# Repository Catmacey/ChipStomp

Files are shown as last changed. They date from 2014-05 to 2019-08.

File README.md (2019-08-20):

ChipStomp Guitar Effects Pedal
==============================

ChipStomp

This is a digital guitar effects pedal based on the Arduino compatible Chipkit DP32 platform.
The project is a merging of a ChipKit DP32 with an Open Music Labs Stompshield in a custom build PCB.

The Chipkit is an arduino compatible platform powered by a 32bit Microchip PIC processor running at 40Mhz with 32Kb RAM and 128Kb flash.  

UPDATE: There is a [3d printable case available for this project](https://github.com/Catmacey/ChipStompCase). 
3D Printed Case

The project is relatively simple in that it limits itself to using the PIC's internal RAM, built in 10bit ADC and utilizes two 8bit PWMs to form a single 16bit output.  Also included is a 128x64px 1.3" OLED to provide a nice user interface.

Currently the following effects are completed.
- **Flanger** : Classic wobbly tape effect.

- **Tremolo** : Low frequency modulation of the source audio.

- **Pitch shift** : Change the pitch (up or down) of the source audio without changing the playback speed.

- **Echo/Delay** : A simple lo-fi delay (700ms Max) that when combined with a bit of analogue feedback provides a nice echo.

- **Bitcrusher** : Reduces the sample rate by ratios down to 1/64 of the source rate, also reduces the bit-depth to create some nice messy sounds.

You can have all or just some of these effect running at the same time with each passing its output onto the next effects input. 

[More information is available on my blog.](http://catmacey.wordpress.com/tag/chipstomp/)

Copyright (C) 2014 Matt Casey : catmacey.com
This program is free software: you can redistribute it and/or modify it under the terms of the GNU General Public License as published by the Free Software Foundation, either version 3 of the License, or (at your option) any later version.
	
This program is distributed in the hope that it will be useful, but WITHOUT ANY WARRANTY; without even the implied warranty of MERCHANTABILITY or FITNESS FOR A PARTICULAR PURPOSE.  See the GNU General Public License for more details.

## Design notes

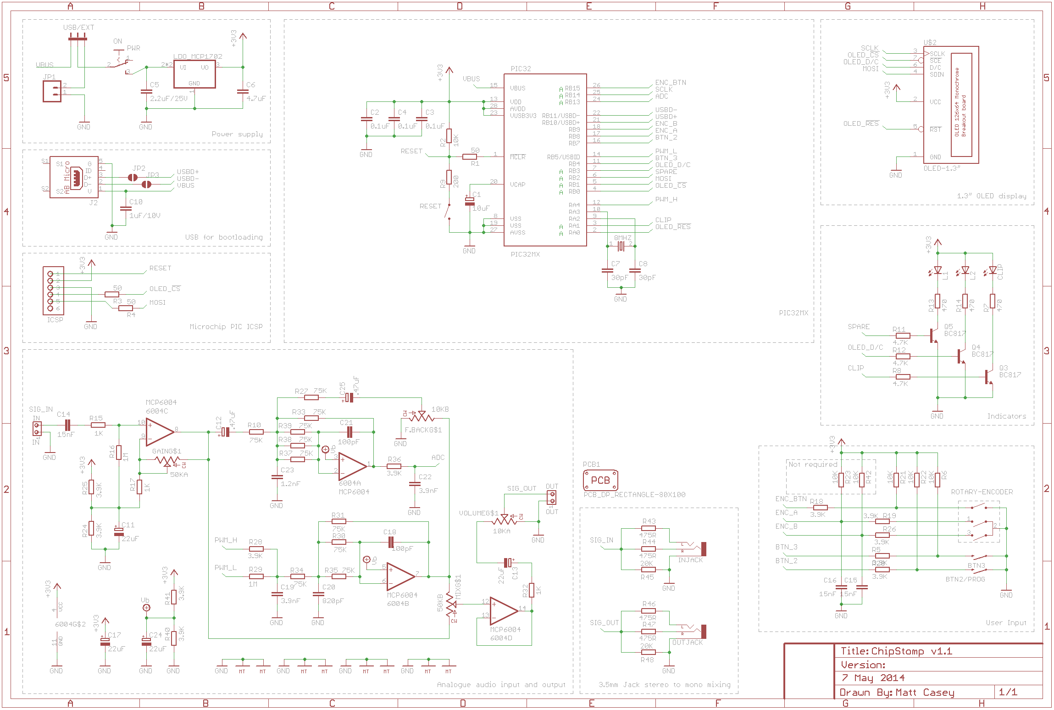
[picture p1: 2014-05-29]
EagleCad/Schematic_v1.1.png

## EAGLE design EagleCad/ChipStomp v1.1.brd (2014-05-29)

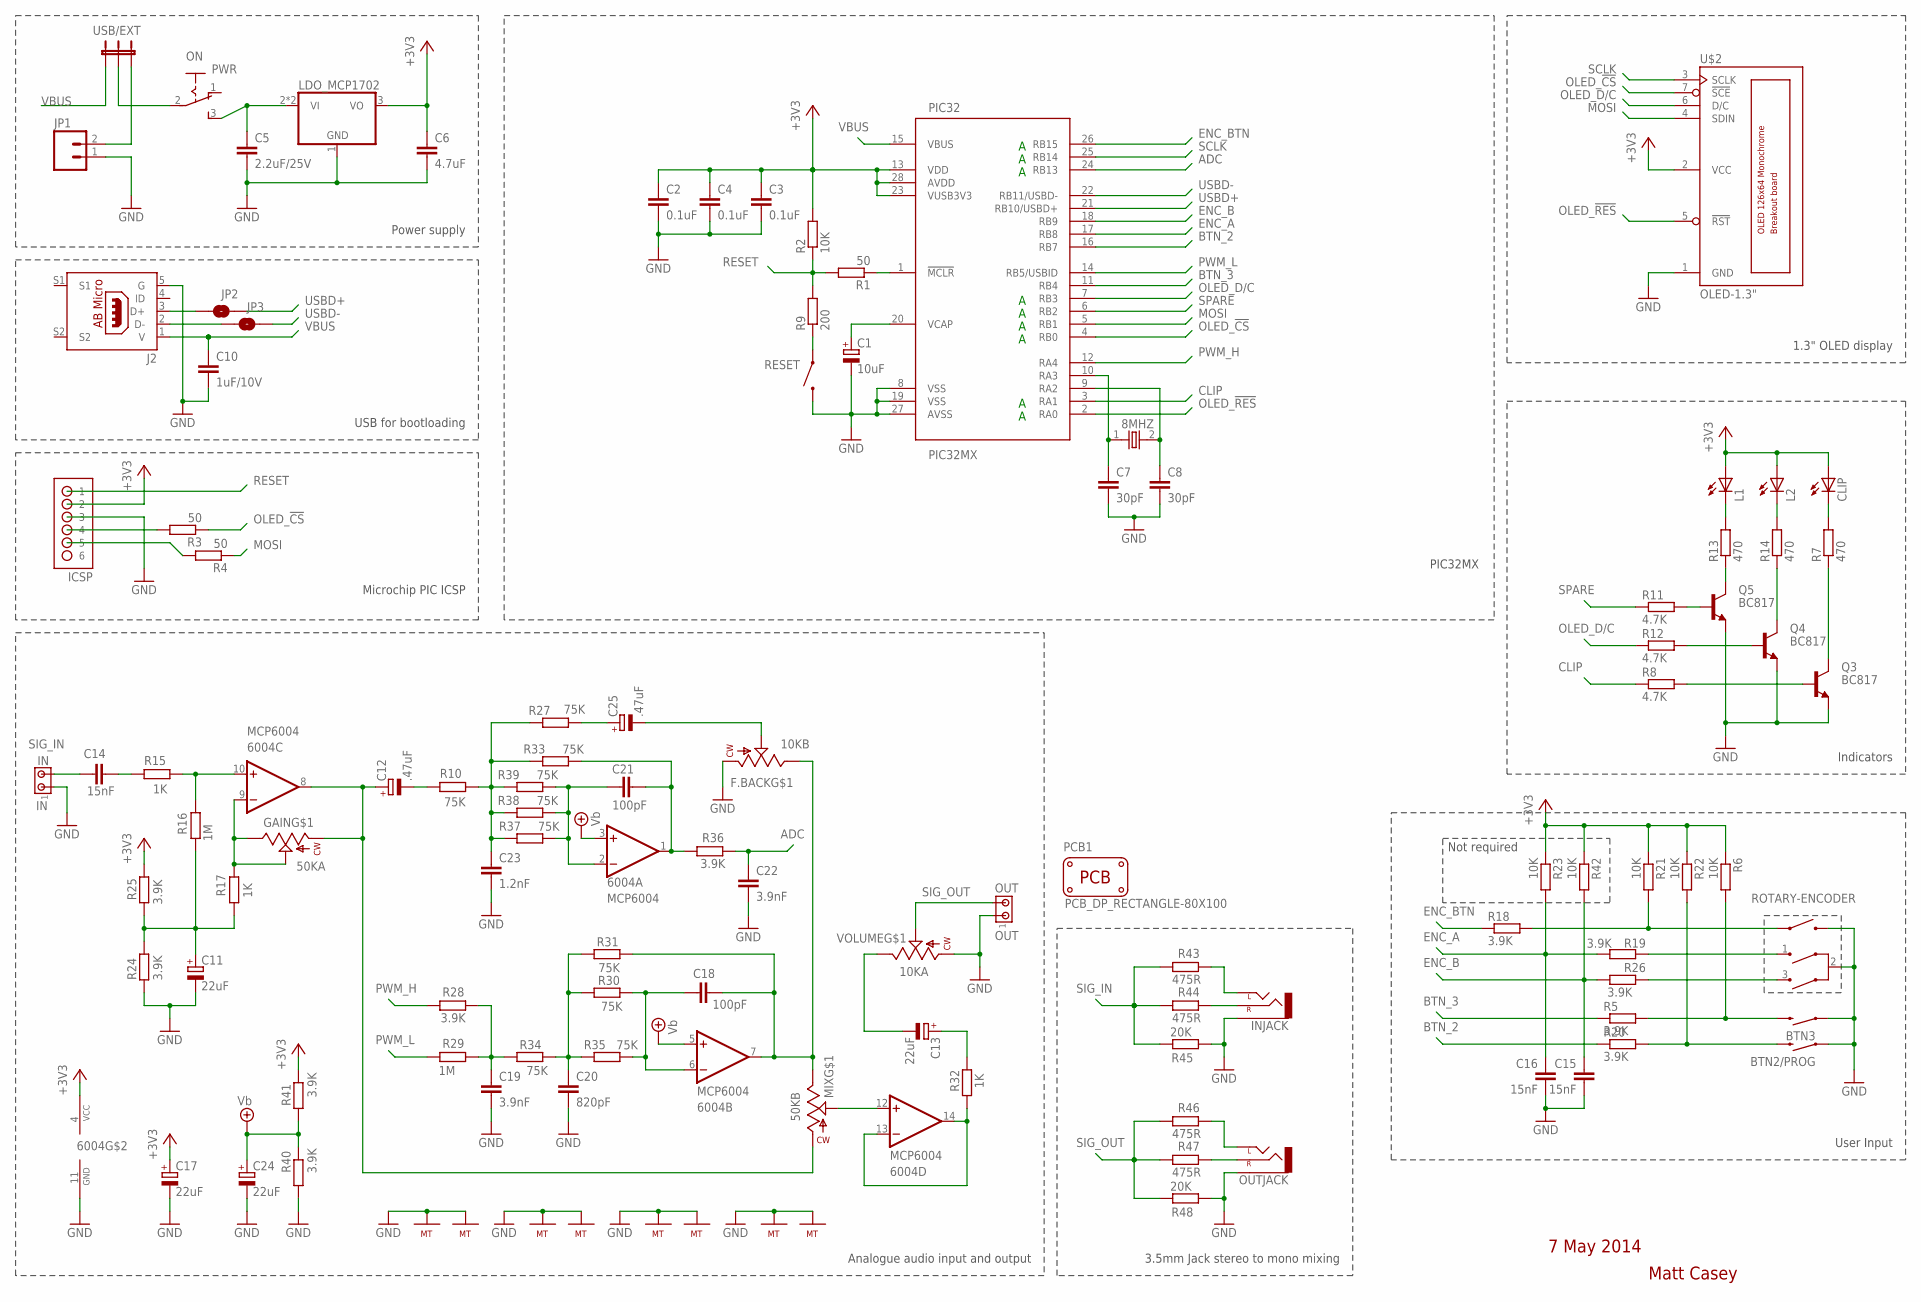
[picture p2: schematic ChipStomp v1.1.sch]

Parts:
8MHZ: OSC-XTAL-HC-49U-SMD; HC-49U
6004: MCP6004; SO-14
BTN2/PROG, BTN3: SWITCH-MOMENTARY-212MM; TACTILE-PTH-12MM
C1: 10uF; A/3216-18R
C2, C3, C4: 0.1uF; C0805K
C5: 2.2uF/25V; C0805K
C6: 4.7uF; C0805K
C7, C8: 30pF; C0805K
C10: 1uF/10V; C0805K
C11, C13, C17, C24: 22uF; 153CLV-0505
C12, C25: .47uF; 153CLV-0405
C14, C15, C16: 15nF; C0805K
C18, C21: 100pF; C0805K
C19, C22: 3.9nF; C0805K
C20: 820pF; C0805K
C23: 1.2nF; C0805K
CLIP: LED-0805; LED-805
F.BACK: 10KB; POT/SINGLE/PANASONIC/VERT
GAIN: 50KA; POT/SINGLE/PANASONIC/VERT
ICSP: No Load; HDR-1X6_OFFSET
IN: IN; JMP/2P/SIP
INJACK: AUDIO-JACKPTH; STEREO_JACK3.5MM_PTH
J2: US-AB-MICRO-TH; WMRU2AB-05FLB2DSR-4.0
JP1: M023.5MM; SCREWTERMINAL-3.5MM-2
JP2, JP3: Straight Male; SJ_2S-TRACE
L1, L2: LED-0805; LED-805
MIX: 50KB; POT/SINGLE/PANASONIC/VERT
ON: PWR; DX_MINI_SPDT_VERTICAL
OUT: OUT; JMP/2P/SIP
OUTJACK: AUDIO-JACKPTH; STEREO_JACK3.5MM_PTH
PCB1: PCB_DP_RECTANGLE-80X100; DP10080_V1
PIC32: PIC32MX; SO-28
Q3, Q4, Q5: BC817; SOT23-BEC
R1, R3, R4: 50; R0805
R2, R6, R21, R22, R23, R42: 10K; R0805
R5, R18, R19, R20, R24, R25, R26, R28, R36, R40, R41: 3.9K; R0805
R7, R13, R14: 470; R0805
R8, R11, R12: 4.7K; R0805
R9: 200; R0805
R10, R27, R30, R31, R33, R34, R35, R37, R38, R39: 75K; R0805
R15, R17, R32: 1K; R0805
R16, R29: 1M; R0805
R43, R44, R46, R47: 475R; R0805
R45, R48: 20K; R0805
RESET: TINY_TACTILEPTH; TINY_TACTILE_PTH
SW1: ROTARY-ENCODER; SURE
U$2: OLED-1.3"; OLED-130-BREAKOUT_2HOLES
U$3: LDO_MCP1702; SOT89
USB/EXT: JUMPER-3PTH; 1X03
VOLUME: 10KA; POT/SINGLE/PANASONIC/VERT

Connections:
+3V3: 6004.4 (VCC), C2.1, C3.1, C4.1, C6.1, C17.+, CLIP.A, ICSP.2, L1.A, L2.A, PIC32.13 (VDD), PIC32.23 (VUSB3V3), PIC32.28 (AVDD), R2.2, R6.1, R21.1, R22.1, R23.1, R25.1, R41.1, R42.1, U$2.2 (VCC), U$3.3 (VO)
ADC: C22.1, PIC32.24 (RB13), R36.1
BTN_2: PIC32.16 (RB7), R20.1
BTN_3: PIC32.11 (RB4), R5.1
CLIP: PIC32.3 (RA1), R8.1
ENC_A: C16.1, PIC32.17 (RB8), R19.1, R23.2
ENC_B: C15.1, PIC32.18 (RB9), R26.1, R42.2
ENC_BTN: PIC32.26 (RB15), R18.1
GND: 6004.11 (GND), BTN2/PROG.1, BTN3.1, C1.-, C2.2, C3.2, C4.2, C5.2, C6.2, C7.2, C8.2, C10.2, C11.-, C15.2, C16.2, C17.-, C19.2, C20.2, C22.2, C23.2, C24.-, F.BACK.P$1 (1), F.BACK.P$4 (MT), F.BACK.P$5 (MT), GAIN.P$4 (MT), GAIN.P$5 (MT), ICSP.3, IN.1, INJACK.S (SLEEVE), INJACK.S@1 (SLEEVE), J2.5 (G), JP1.1, MIX.P$4 (MT), MIX.P$5 (MT), OUT.1, OUTJACK.S (SLEEVE), OUTJACK.S@1 (SLEEVE), PIC32.8 (VSS), PIC32.19 (VSS), PIC32.27 (AVSS), Q3.E, Q4.E, Q5.E, R24.2, R40.2, R45.2, R48.2, RESET.2 (B), SW1.2 (COMMON), SW1.A (B), U$2.1 (GND), U$3.1 (GND), VOLUME.P$1 (1), VOLUME.P$4 (MT), VOLUME.P$5 (MT)
MOSI: PIC32.5 (RB1), R4.1, U$2.4 (SDIN)
unnamed: PIC32.1 (!MCLR), R1.1
unnamed: BTN3.3 (2), R5.2, R6.2
unnamed: Q3.C, R7.1
unnamed: Q3.B, R8.2
unnamed: CLIP.C, R7.2
unnamed: INJACK.L (LEFT), INJACK.L@1 (LEFT), R43.1
unnamed: INJACK.R (RIGHT), R44.1
unnamed: ON.2, USB/EXT.2
unnamed: OUTJACK.L (LEFT), OUTJACK.L@1 (LEFT), R46.1
unnamed: R9.1, RESET.1 (A)
unnamed: C1.+, PIC32.20 (VCAP)
unnamed: OUTJACK.R (RIGHT), R47.1
unnamed: C14.2, R15.2
unnamed: JP1.2, USB/EXT.3
unnamed: 6004.10 (+IN), R15.1, R16.2
unnamed: Q5.B, R11.2
unnamed: Q5.C, R13.1
unnamed: Q4.C, R14.1
unnamed: Q4.B, R12.2
unnamed: 6004.8 (OUT), C12.+, GAIN.P$1 (1), MIX.P$1 (1)
unnamed: J2.2 (D-), JP3.1
unnamed: 6004.9 (-IN), GAIN.P$2 (2), GAIN.P$3 (3), R17.2
unnamed: L1.C, R13.2
unnamed: L2.C, R14.2
unnamed: C12.-, R10.2
unnamed: R18.2, R21.2, SW1.B (A)
unnamed: BTN2/PROG.3 (2), R20.2, R22.2
unnamed: C23.1, R10.1, R27.2, R33.2, R37.2, R38.2, R39.2
unnamed: 6004.2 (-IN), C21.1, R37.1, R38.1, R39.1
unnamed: 6004.1 (OUT), C21.2, R33.1, R36.2
unnamed: C11.+, R16.1, R17.1, R24.1, R25.2
unnamed: C19.1, R28.1, R29.1, R34.2
unnamed: C20.1, R30.2, R31.2, R34.1, R35.2
unnamed: 6004.6 (-IN), C18.1, R30.1, R35.1
unnamed: C25.+, R27.1
unnamed: 6004.7 (OUT), C18.2, F.BACK.P$3 (3), MIX.P$3 (3), R31.1
unnamed: C13.+, R32.1
unnamed: C13.-, VOLUME.P$3 (3)
unnamed: R19.2, SW1.1 (SIG1)
unnamed: R26.2, SW1.3 (SIG2)
unnamed: C25.-, F.BACK.P$2 (2)
unnamed: 6004.12 (+IN), MIX.P$2 (2)
unnamed: 6004.13 (-IN), 6004.14 (OUT), R32.2
OLED_!CS: PIC32.4 (RB0), R3.1, U$2.7 (!SCE)
OLED_!RES: PIC32.2 (RA0), U$2.5 (!RST)
OLED_D/C: PIC32.7 (RB3), R12.1, U$2.6 (D/C)
OSC1/CLKI/RPA2/RA2: 8MHZ.2, C8.1, PIC32.9 (RA2)
OSC2/CLKO/RPA3/PMA0/RA3: 8MHZ.1, C7.1, PIC32.10 (RA3)
PGC: ICSP.5, R4.2
PGD: ICSP.4, R3.2
PWM_H: PIC32.12 (RA4), R28.2
PWM_L: PIC32.14 (RB5/USBID), R29.2
RESET: ICSP.1, R1.2, R2.1, R9.2
SCLK: PIC32.25 (RB14), U$2.3 (SCLK)
SIG_IN: C14.1, IN.2, R43.2, R44.2, R45.1
SIG_OUT: OUT.2, R46.2, R47.2, R48.1, VOLUME.P$2 (2)
SPARE: PIC32.6 (RB2), R11.1
USBD+: J2.3 (D+), JP2.1, JP2.2, PIC32.21 (RB10/USBD+)
USBD-: JP3.2, PIC32.22 (RB11/USBD-)
VBUS: C10.1, J2.1 (V), PIC32.15 (VBUS), USB/EXT.1
VIN: C5.1, ON.3 (S), U$3.2 (VI), U$3.4 (VI)
VREF: 6004.3 (+IN), 6004.5 (+IN), C24.+, R40.1, R41.2

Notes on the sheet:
User Input
Power supply
Indicators
3.5mm Jack stereo to mono mixing
Analogue audio input and output
USB for bootloading
Microchip PIC ICSP
1.3" OLED display
Matt Casey
PIC32MX
7 May 2014
Not required

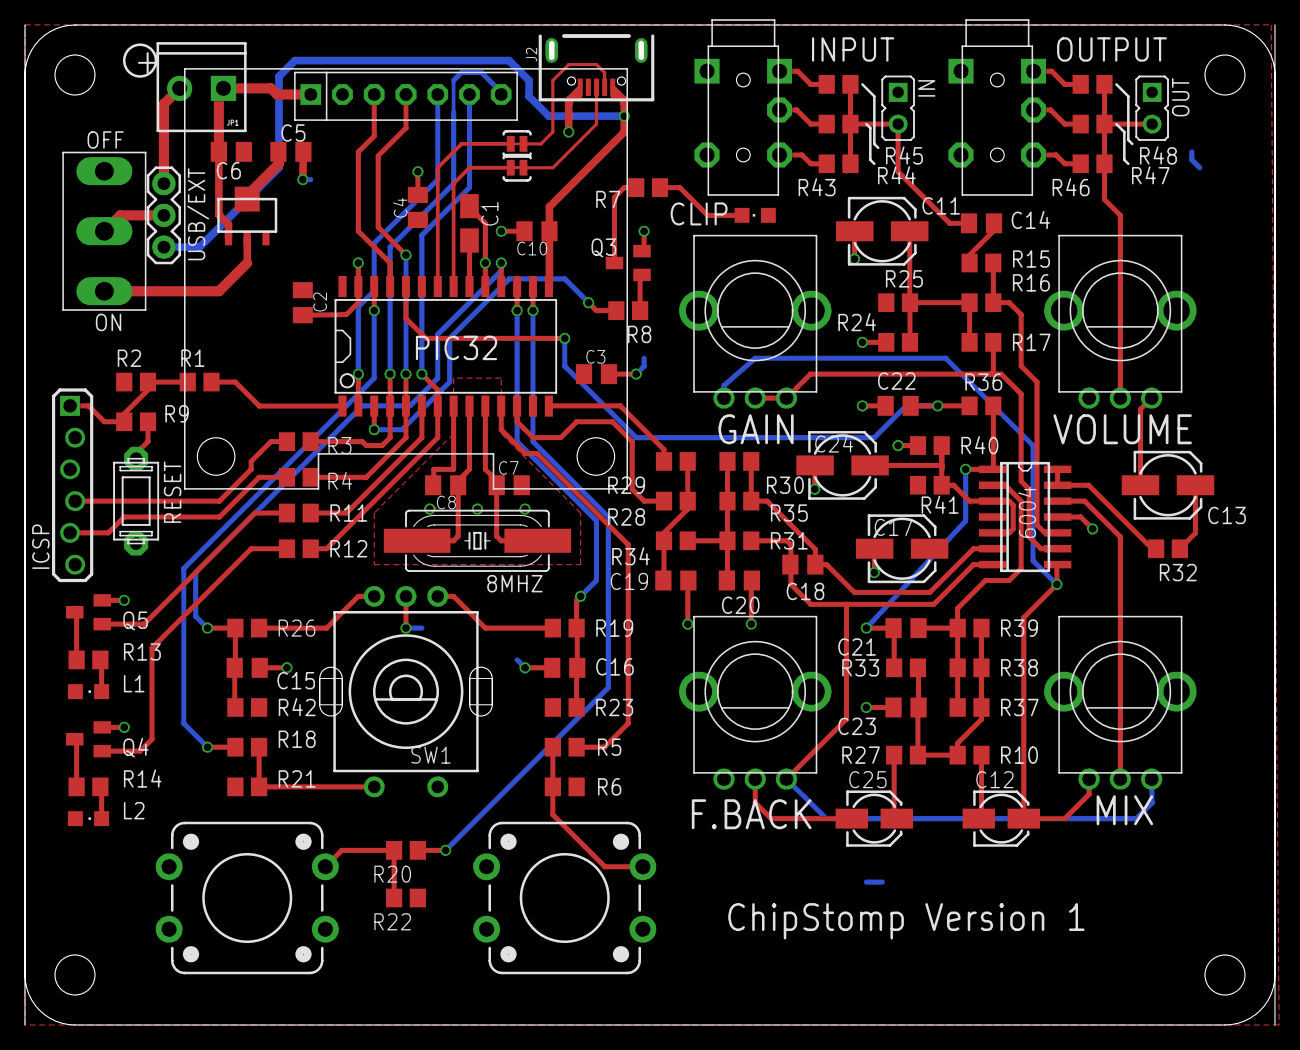
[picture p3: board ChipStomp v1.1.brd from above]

Board: 2 copper layers, 100.0 x 80.0 mm, 103 parts (0 on the bottom side), 72 nets.

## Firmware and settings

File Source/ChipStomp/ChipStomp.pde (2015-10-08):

// 
// ChipStomp
// Multifunction audio effects processor built on a Microchip PIC32MX
//

/*
	Reads mono audio in on the ADC
	Processes it with one or more digital effects
	Sends it out on two 8bit PWM summed together to form a 16bit mono output

	Hardware is a combination of the ChipKit DP32 and an Open Labs StompShield
	StompShield : Shield http://www.openmusiclabs.com/projects/stomp-shield/
	DP32 : https://digilentinc.com/Products/Detail.cfm?NavPath=2,892,1174&Prod=CHIPKIT-DP32
	Display is a 128x64 px SH1106 based OLED

	Copyright (C) 2014 Matt Casey : catmacey.com

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
	This program is distributed in the hope that it will be useful,
	but WITHOUT ANY WARRANTY; without even the implied warranty of
	MERCHANTABILITY or FITNESS FOR A PARTICULAR PURPOSE.  See the
	GNU General Public License for more details.
*/

#define VERSION "1.0"

#include <PLIB.h>  // Use this Microchip library to make access to the peripherals easier
#include <DSPI.h>
#include <Adafruit_GFX.h>
#include <Catmacey_SH1106.h>
#include "config.h"

// Include the font's you want here
#include "LiberationSans10.c"
// #include "LiberationMono11.c"
#include "DejaVuSans12.c"

// Make an array of pointers to FONT_INFOs for each font that you want
// Don't forget to put a NULL at the end
const FONT_INFO *g_font_table[] = {
		&liberationSans_10ptFontInfo
	, &dejaVuSans_12ptFontInfo
	, NULL
};


// Each effect is it's own self contained module
#include "Effect_typeDefs.h"
#include "effect_tremolo.h"
#include "effect_flanger.h"
#include "effect_echo.h"
#include "effect_bitcrush.h"
#include "effect_dummy.h"
#include "effect_pitchshift.h"
// #include "effect_sinus.h"

// Effects stack : Important that the last one is NULL so that we are a the end.
Effect_t *g_effects[] = {
			&effect_Tremolo
		, &effect_Flanger
		, &effect_Pitchshift
		, &effect_Bitcrush
		, &effect_Echo
		// , &effect_Sinus
		, NULL
	};

// TODO : Create a distortion effect with configuable threshold, shoft/hard clipping.
// TODO : Add a metronome effect (last in the chain) with config bpm/volume.
// TODO : Improve input sampling by oversampling (running ADC at faster rate then averaging the results)
// TODO : Add "cost" to each effect (measured using LA) to allow user to select effects that fit withing the overall CPU budget.
// TODO : Allow user to change order or load-out of effects to allow duplication of effects?
// TODO : Allow user to save their current config and effect values. Provide interface to load these saves.
// TODO : Bandpass|HP|LP filters? Might be too CPU intensive to run concurrent with other effects. (Hence need for cost/budget)

// Digilent hardware SPI library
DSPI0 spi;
// OLED Driver : Uses Adafruit GFX library
Catmacey_SH1106 display(OLED_DC, OLED_RESET, OLED_CS, &spi, g_font_table);

// Global for holding the state of the various inputs
InputState_t g_input;
// Global struct for holding VU values. Used by both ISR and main()
volatile VUMeter_t g_meter;

// USed for managing the input 
enum btnmode_t {START, TOGGLE, HOLD};
// Only used for debugging above
const char *btnmode_str[] = {"Nada","Toggle","Hold"};


// Arduino setup routine
void setup() {
	// set the digital pin as output:
	mPORTASetPinsDigitalOut(DACHI_BIT | CLIP_BIT | OLEDRES_BIT);
	mPORTBSetPinsDigitalOut(OLEDCS_BIT | MOSI_BIT | OLEDDC_BIT | DACLO_BIT | SCLK_BIT);
	mPORTBSetPinsDigitalIn(ENCA_BIT | ENCB_BIT | BTNEFFECT_BIT | BTNSELECT_BIT | ENCBTN_BIT);
	
	// Set up PPS for OC (Note: Arduino pin numbers)
	mapPps(DACH, PPS_OUT_OC4);
	mapPps(DACL, PPS_OUT_OC2);

	// DPSPI.begin() sets up PPS for us

	// Setup change notification with pullups for the buttons and rotary encoder with pullups for the rotary encoder
	// | CNB15_ENABLE
	mCNBOpen(CNB_ON, CNB4_ENABLE | CNB7_ENABLE | CNB8_ENABLE | CNB9_ENABLE, CNB8_PULLUP_ENABLE | CNB9_PULLUP_ENABLE);
	// Read the port to start the ball rolling
	mPORTBRead();
	// Start CN interrupt
	ConfigIntCNB(CHANGE_INT_ON | _CN_IPL_IPC);
	
	// Setup the two 8bit PWM outputs
	OpenTimer3(T3_ON | T3_PS_1_1, 256);
	OpenOC4(OC_ON | OC_TIMER3_SRC | OC_PWM_FAULT_PIN_DISABLE, 0, 0);
	OpenOC2(OC_ON | OC_TIMER3_SRC | OC_PWM_FAULT_PIN_DISABLE, 0, 0);
	delay(1);

	// Setup ADC
	CloseADC10();
	// Set ADC input as AN11 and reference as GND
	SetChanADC10( ADC_CH0_POS_SAMPLEA_AN11 | ADC_CH0_NEG_SAMPLEA_NVREF);
	// Configure and turn on ADC
	OpenADC10( 
			// ouTput in integer | trigger mode auto | enable autosample 
			ADC_FORMAT_SIGN_INT32 | ADC_CLK_AUTO | ADC_AUTO_SAMPLING_ON 
			//ADC ref internal | disable offset test | disable scan mode | Interrupt after X samples | use dual buffers | use alternate mode
		, ADC_VREF_AVDD_AVSS | ADC_OFFSET_CAL_DISABLE | ADC_SCAN_OFF | ADC_SAMPLES_PER_INT_1 | ADC_ALT_BUF_OFF | ADC_ALT_INPUT_OFF 
			// use ADC PB clock| set sample time | auto
		, ADC_CONV_CLK_PB | ADC_SAMPLE_TIME_31 
			// Enable only AN11
		, ENABLE_AN11_ANA
			// Don't scan channels (we're only using a single channel)
		, SKIP_SCAN_ALL  
	);
	// Set the ADC conversion clock pretty fast.
	// This results in a fast sampling speed. (I think)
	AD1CON3bits.ADCS = 0x01;
	EnableADC10();

	// Setup timer to trigger ISR for main processing routine.
	// Timer is set to the desired sample rate (eg. 44.1khz)
	ConfigIntTimer1(T1_INT_ON | T1_INT_PRIOR_3);
	OpenTimer1(T1_ON | T1_PS_1_1, F_CPU / SAMPLERATE);

	// Set the default duty cycles for the PWMs
	SetDCOC4PWM(0x7f); 
	SetDCOC2PWM(0xff); 
	

	// Setup hardware SPI. Not we're not using MISO
	spi.begin(0, SPI_MOSI, OLED_CS);
	spi.setSpeed(10000000);
 	
 	// Initialize the OLED using the internal DC/DC convertor
	display.begin();
	// Load the spashscreen into the displaybuffer
	display.drawBitmap(0, 0, g_splashscreen, 128, 64, 1);
	display.display(); // show splashscreen
	
	// Setup serial for debugging
	Serial.begin(115200);
	// Wait. Cos I read that you must wait after enabling serial debugging before you use it.
	// We use this delay to show the splashscreen for a bit
	delay(2000);
	
	// init done
}
	
void loop() {
	//Serial.println("loop.start");
	uint8_t idx = 0;
	uint8_t effectCount = 0;
	uint8_t somethinghappened = false;
	int tmp, addr = 0;
	
	uint16_t ctr;

	btnmode_t mode = START;  // Default button mode
	char buff[100];
	Effect_t *currentEffect;
	Effect_t **currentAddr = &g_effects[0]; // Get Ptr2ptr in array pos zero
	// Start with currentEffect as first one
	currentEffect = *currentAddr;
	InputState_t input;

	mPORTAToggleBits(CLIP_BIT);
	display.setTextColor(1);
	display.setCursor(2,53);
	display.print("Version ");
	display.print(VERSION);
	display.display();

	delay(500);
	mPORTAToggleBits(CLIP_BIT);
	delay(500);
	display.clearDisplay();   // clears the buffer
	display.display();
	mPORTAToggleBits(CLIP_BIT);

	// Set this to cause the display to be rendered on the first run through
	somethinghappened = true;

	// Loop here. Not using the Arduino loop().
	while(1){
		// Grab a copy : It changes fast
		input = g_input;
		if(input.btn_diff.complete){
			/*
				TODO: Would like to add a timeout so that if the Effect
				button is held for too long then it drops back to START
				This might be handy where you press the button in error
				, just hold it until it times out.
				Could maybe also have a timeout for the Effect's featureIdx.
				After a period of no input it would reset to the dummy feature (0)
			*/ 
			/*
				TODO: Might be useful to add some sort of "acceleration" factor
				to the input from the encoder. It takes ages to go from end to end 
				of the scale. Maybe if the encoder delta is > X we double it?
			*/
			switch(mode){
				case TOGGLE:
				case HOLD:{
					if(input.btn_diff.effect & !input.btn_state.effect){
						// Released the effect button
						if(mode == HOLD){
							// No other button was pressed
							// Serial.println("Switch");
							// Each press should cycle through the available g_effects
							//Serial.print("Switch Effect to ");
							currentAddr++;
							if(*currentAddr == 0){
								currentAddr = &g_effects[0];
							}
							currentEffect = *currentAddr;
							// Serial.println(currentEffect->name);
							// sprintf(buff, "currentEffect size:%d, addr:%p, ptrAddr:%x \n", sizeof(*currentEffect), currentEffect, *currentAddr);
							// Serial.println(buff);
							// Flag that something has happened
							somethinghappened = true;        
						}
						mode = START;
					}else if(input.btn_diff.select & !input.btn_state.select){
						// Released the select button
						//Serial.println("Toggle");
						currentEffect->toggleOnOff();
						//Serial.print(currentEffect->name);
						//Serial.println(currentEffect->state?" ON":" OFF");
						// Switch mode to indicate that we've done this
						mode = TOGGLE;
						// Flag that something has happened
						somethinghappened = true;
					}

					break;
				}
				case START:{
					// No other buttons held : This is the start of something.
					if(input.btn_diff.effect & input.btn_state.effect & !input.btn_state.select){
						// Pressed the effect button (ignore if select is pressed)
						mode = HOLD;
					}
					if(input.btn_diff.select & input.btn_state.select){
						// Released the select button
						//Serial.println("Next feature");
						currentEffect->nextFeature();
						// Flag that something has happened
						somethinghappened = true;
					}


					break;
				}
			}
			//sprintf(buff, "Now Mode:%d:%s", mode, btnmode_str[mode]);
			//Serial.println(buff);

			// Need to clear btn_diff once you've "used" it
			g_input.btn_diff.complete = 0;
			
		}
		if(input.encoder.value != 0){
			//Serial.print("Encoder:");
			//Serial.print(input.encoder.value, DEC);
			input.encoder.value *= abs(input.encoder.value);
			//Serial.print(" : ");
			//Serial.println(input.encoder.value, DEC);
			// Encoder has been twiddled
			if(input.btn_state.effect){
				// Choose effect
				// lfo_step_alter(input.encoder.value);
			}else{
				currentEffect->adjustFeature(input.encoder.value);
			}

			// Set the value to zero once used
			g_input.encoder.value = 0;
			// Flag that something has happened
			somethinghappened = true;
		}

		if(somethinghappened){
			// Output a report of current state
			// The first line is the same for all effects
			display.clearDisplay();
			display.setCursor(0,DISP_FEAT_INDENT);
			display.setTextColor(1);
			display.setFont(1);
			display.print(currentEffect->name);
			display.setFont(0);
			display.drawFastHLine(0,17,DISP_FEAT_W,1);
			if(currentEffect->state){
				display.setTextColor(0);
				display.fillRect(98,0,25,18,1);
				display.setCursor(105,2);
				display.print("on");
			}else{
				display.drawRect(98,0,25,18,1);
				display.setCursor(103,2);
				display.print("off");
			}
			display.setTextColor(1);
			// Other lines are specifc to the effect and its internal settings
			display.setCursor(DISP_FEAT_INDENT,DISP_FEAT_Y);
			//display.setTextSize(1);
			currentEffect->report();
			somethinghappened = false;
		}

		// Render the VU bars
		renderVU();

		// Now render the whole display buffer
		display.display();

		delay(35);
		mPORTBToggleBits(BIT_2);
	} //while
}

// Render the input and output V meters
void renderVU(){
	uint8_t idx, yi, yo, ypo, ypi;
	uint32_t sum_out, sum_in;

	sum_in = 0;
	sum_out = 0;
	// First do the averaging
	for(idx=0; idx < VUTICKLEN; idx++){
		sum_in += abs(g_meter.input[idx]);
		sum_out += abs(g_meter.output[idx]);
	}

	sum_in /= VUTICKLEN;
	sum_out /= VUTICKLEN;
	// The sums should now contain an average of the last N samples
	// Scale is 15bits (half a 16bit signed int)
	// Shift them down to 6 bits to fit in vertical scale of screen
	sum_in >>= 9;
	sum_out >>= 9;
	yi = 63-sum_in;
	yo = 63-sum_out;

	if(sum_in > g_meter.peak_in) g_meter.peak_in = sum_in;
	else if(g_meter.peak_in > 1) g_meter.peak_in-=2;

	if(sum_out > g_meter.peak_out) g_meter.peak_out = sum_out;
	else if(g_meter.peak_out > 1) g_meter.peak_out-=2;

	ypi = 63-g_meter.peak_in;
	ypo = 63-g_meter.peak_out;

	// Clear space
	display.drawFastVLine(124,0,63,0);
	display.drawFastVLine(125,0,63,0);
	display.drawFastVLine(126,0,63,0);
	display.drawFastVLine(127,0,63,0);
	// VU input
	display.drawFastHLine(124,ypi,2,1);
	display.drawFastVLine(124,yi,sum_in,1);
	display.drawFastVLine(125,yi,sum_in,1);
	
	display.drawFastHLine(126,ypo,2,1);
	display.drawFastVLine(126,yo,sum_out,1);
	display.drawFastVLine(127,yo,sum_out,1);
	
}


// Returns a pergentage value (float)
float percentage(uint16_t value, uint16_t max, uint16_t min){
	float result, frac;
	uint16_t range, offset;
	range = max - min;
	offset = value - min;
	frac = (float)offset/range;
	result = frac * 100;
	return result;
}

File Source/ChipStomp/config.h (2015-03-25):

/*
	Main header file
*/

#ifndef __Config__
#define __Config__

#include <stdint.h> 

// #define SAMPLERATE 44100    // Hz
// #define SAMPLETIME 0.02267 // Approx sample time in mS 
#define SAMPLERATE 40000
#define SAMPLETIME 0.025
// #define SAMPLERATE 32000  
// #define SAMPLETIME 0.03125
#define CLIPLEVEL 31000  // Full range is +32767 to -32767 but this is the level we light the LED at.
#define CLIPHARD 32767

// PIC port/pins
// PORT A
#define OLEDRES_BIT BIT_0  // RA0
#define CLIP_BIT    BIT_1  // RA1
// BIT_2 Osc
// BIT_3 Osc
#define DACHI_BIT   BIT_4  // RA4

// PORT B
// Outputs
#define OLEDCS_BIT  BIT_0
#define MOSI_BIT    BIT_1   // RB1
// BIT_2 Spare
#define OLEDDC_BIT  BIT_3   // RB3
#define DACLO_BIT   BIT_5   // RA5
#define SCLK_BIT    BIT_14

// Inputs
#define BTNSELECT_BIT BIT_4 // RB4
#define BTNEFFECT_BIT BIT_7 // RB7
#define ENCA_BIT BIT_8 // RB8
#define ENCB_BIT BIT_9 // RB9
#define ENCBTN_BIT BIT_15 // RB15

#define ENC_MASK ENCA_BIT | ENCB_BIT // Mask for encoder inputs
#define BTN_MASK BTNEFFECT_BIT | BTNSELECT_BIT | ENCBTN_BIT // Mask for buttons
#define INPUT_MASK ENC_MASK | BTN_MASK // Mask for all inputs

#define VUTICKLEN 16
#define VUTICKLEN_MASK 0x0f

// Some handy values for screen layout
#define DISP_FEAT_Y 20  // Start point for features area
#define DISP_FEAT_W 123 // MAx width of features area (allowing space for VU meter)
#define DISP_FEAT_INDENT 2  // Start point for features area

// Stupid Arduino pin numbers
#define OLED_RESET 9 // RA0 
#define DACL 0 // RB5 DAC Low byte
#define DACH 18 // RA4 DAC High byte
#define SPI_CLK 7 // RB14
#define OLED_CS 11 // RB0
#define OLED_DC 14 // RB3
#define SPI_MOSI 12 // RB1
#define _DSPI1_MOSI_PIN   12
// End of stupid Arduino pin numbers

#define SYS_FREQ 40000000 // PIC OSC frequency
#define GetSystemClock() SYS_FREQ
#define GetPeripheralClock()    (GetSystemClock() / (1 << OSCCONbits.PBDIV))

// This is used to store button state
// The Port the buttons are on is 16bit but the 
// in our case all the buttons are on the lower byte
typedef union {
  uint8_t complete;
  struct {
    unsigned :4;
    unsigned select:1;
    unsigned :1;
    unsigned :1;
    unsigned effect:1;
  };
} ButtonState_t;

// This is used to store the input
typedef struct {
  struct {
    int16_t value; // Accumulated value of encoder input. Set to 0 once actioned
    uint8_t state; // Current state, used in ISR decoding
  } encoder;
  ButtonState_t btn_state; // 1 = pressed
  ButtonState_t btn_diff; // 1 = different from last time
  uint32_t btn_timer; // Could use this to determine how long since last input...
} InputState_t;

// This is used to store the input and output VU Meter
typedef struct {
  int16_t input[VUTICKLEN];
  int16_t output[VUTICKLEN];
  uint8_t peak_in;
  uint8_t peak_out;
  uint8_t tick;
} VUMeter_t;


// Sinewave : 1024 value array of signed 16bit integers
const int16_t g_sinewave[] = {
  #include <sinetable.inc>
};

// Splash screen
const uint8_t g_splashscreen[] = {
  #include <splashscreen.inc>
};


// Returns the percentage value of value between the min and max range
extern float percentage(uint16_t value, uint16_t max, uint16_t min);

#endif

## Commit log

2014-05-29 Initial project creation.
    First upload of project description and Eagle Cad schematics and board
    layout
    [ChipStomp v1.1.brd, ChipStomp v1.1.sch]
2014-10-10 Added bootloader HEX
    Added compiled HEX of the ChipStomp specific bootloader.
    It's a modified Chipkit DP32 bootloader with the buttons configured as
    pulled high - active low, rather than pulled low - active high.
    Also added the BoardConfig.h from the Chipkit bootloader project
    modified to include the Chipstomp board definition.
2015-03-25 Changed sample rate to 40k
    Also a few updates to comments and minor changes.

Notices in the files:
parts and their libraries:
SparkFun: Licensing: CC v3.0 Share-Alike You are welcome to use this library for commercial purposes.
